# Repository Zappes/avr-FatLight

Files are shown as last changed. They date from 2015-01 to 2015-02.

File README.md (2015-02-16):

The FatLight
======================================

What Is this?
-------------
Short: It's a controller board for RGB LED strips that has a bluetooth and some GPIO pins.

Long: I recently ordered everything needed for the creation of PCBs, i.e. a UV exposure unit,
an etching apparatus, chemicals, boards, the works. As a first project, I wanted to do something
that I could use, that I understood from the electronics perspective and that could easily be
done on a one-sided PCB without solder mask. A controller for RGB strips seemed to be a good idea, so here we go. :)

**WARNING IF YOU WANT TO BUILD THIS**
Make sure that the pinout of your Bluetooth module matches the pinout on the board. I have three different HC-05 modules in my parts bin, and every type has a different pinout ... This sucks enormously, and if I didn't have those modules lying around, I'd use a pure HC-05 module instead of the breakouts i have now.

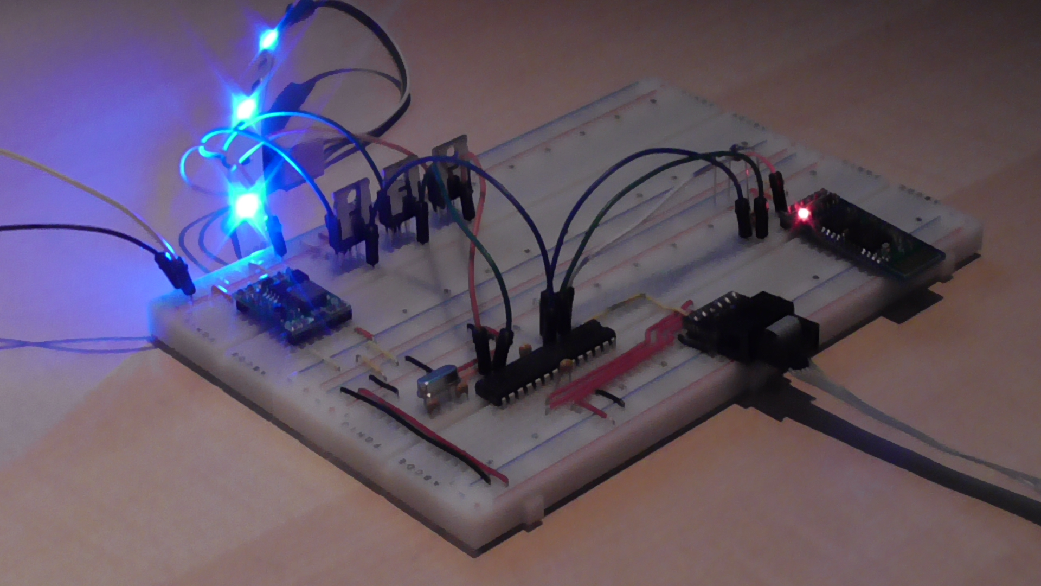
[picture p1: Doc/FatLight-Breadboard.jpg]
Image of the FatLight prototype


How can I control it?
---------------------
It's simple. Connect to the FatLight using a serial terminal over the Bluetooth connection, connection parameters are 9600 8N1, no handshake. The modules have their default pin set to 1234, so use that pin. After connecting, the following commands are supported:

| Command | Parameter | Description |
|---|---|---|
| status | | Prints the current settings. |
| mode | 0-2 | 0: direct color, 1: fade, 2: random |
| on | | Switches the light on | 
| off | | Switches the light off |
| step | 00-FF | Size of the fading steps when fading  |
| set | color | Sets the target color in mode 0 and 1 |
| delay | 00-FF | Greater delays make slower fades |
| level | 00-FF | Brightness in mode 2; 0 is random |
| store | 00-05 | Store current settings in slot 0-5 |
| load | 00-05 | Load settings from slot 0-5 | 
| bt_getname | | Prints the name of the BT module |
| bt_setname | string | Sets the name of the BT module |
| bt_getpass | | Prints the current BT PIN |
| bt_setpass | string | Sets the BT PIN; best use 4 digits |

Color parameters are given as 24 bit hex codes, i.e. 00FF00 for green. Other numeric parameters are also in hex notation. String parameters may never contain whitespace.

Where can I learn more?
-----------------------
[There's a playlist on Youtube.](https://www.youtube.com/playlist?list=PLFFlJlvZ--Pn7IzDO5DFNhvppb0ZImLEq) It's in German, I'm afraid.

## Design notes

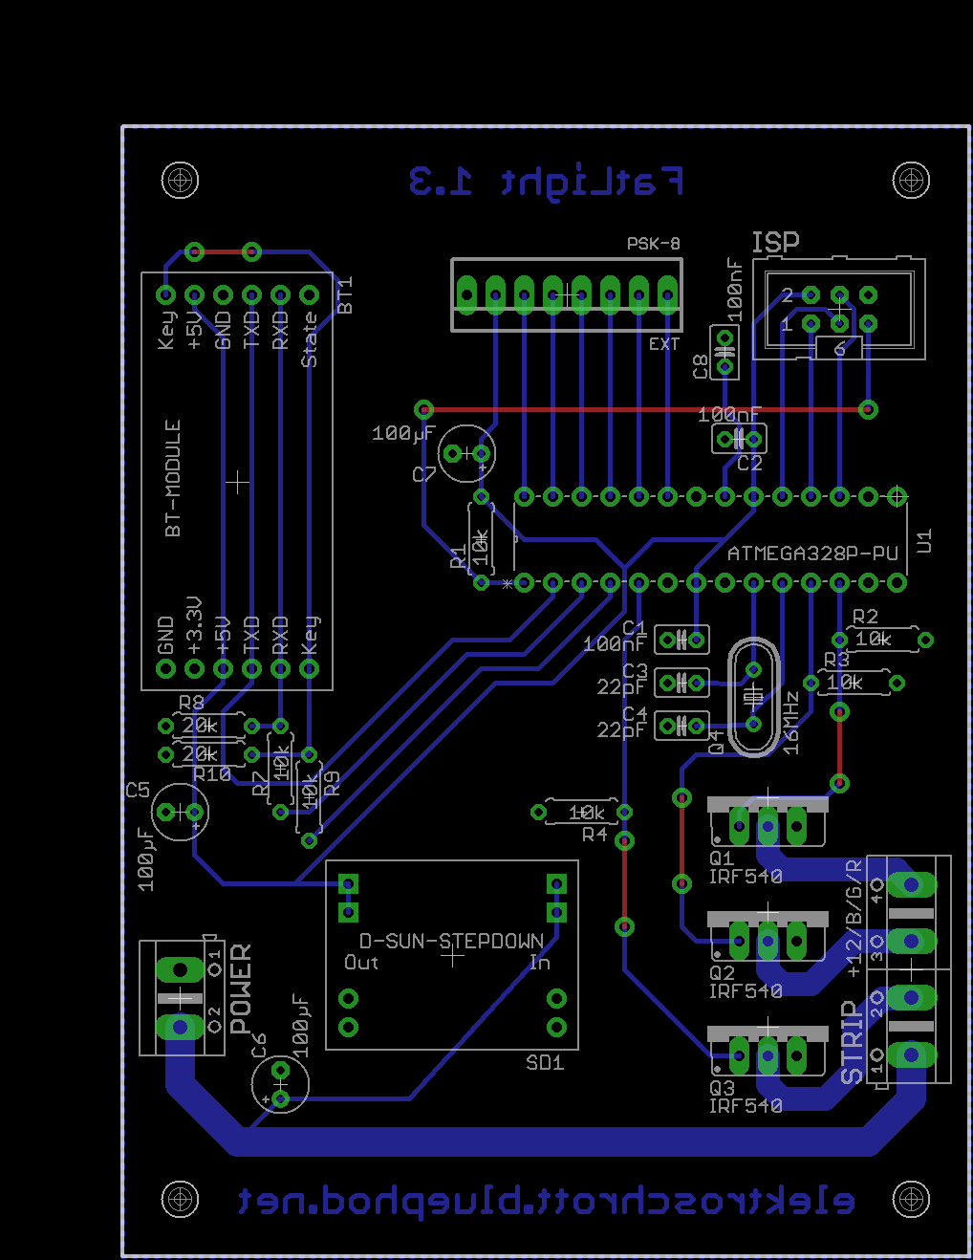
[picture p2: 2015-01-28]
Doc/FatLight-Layout.png

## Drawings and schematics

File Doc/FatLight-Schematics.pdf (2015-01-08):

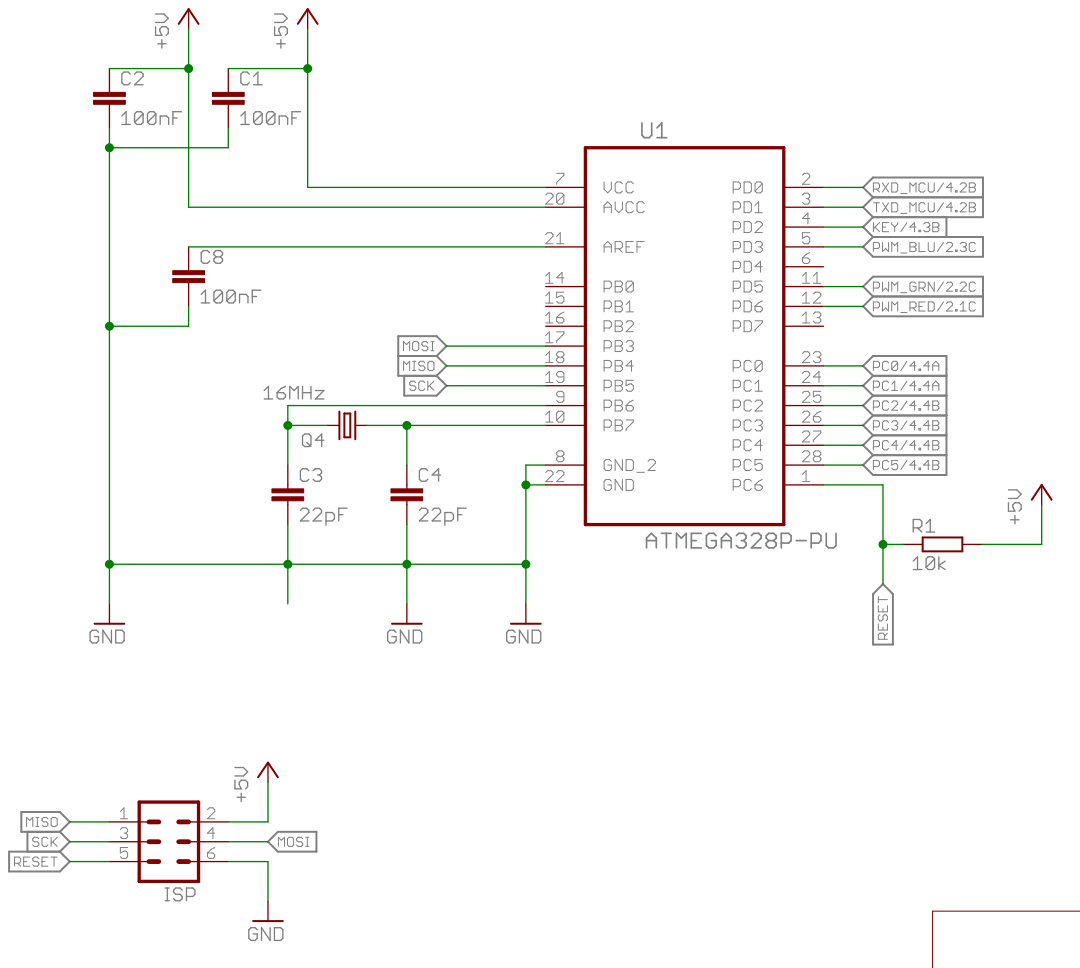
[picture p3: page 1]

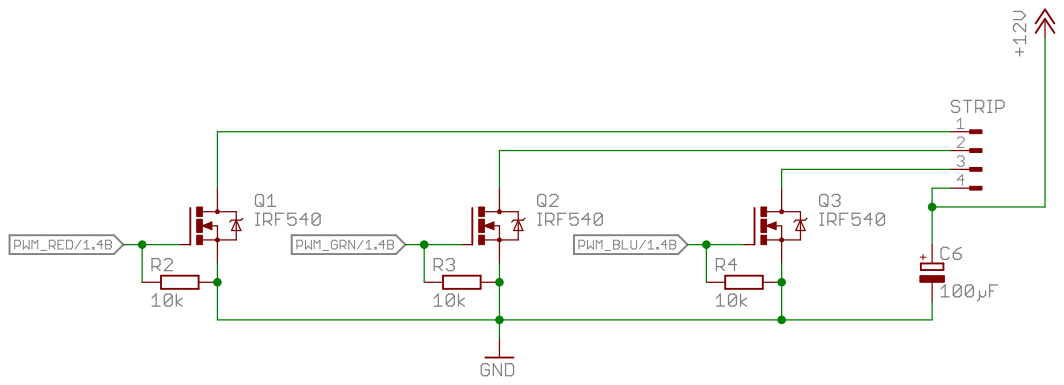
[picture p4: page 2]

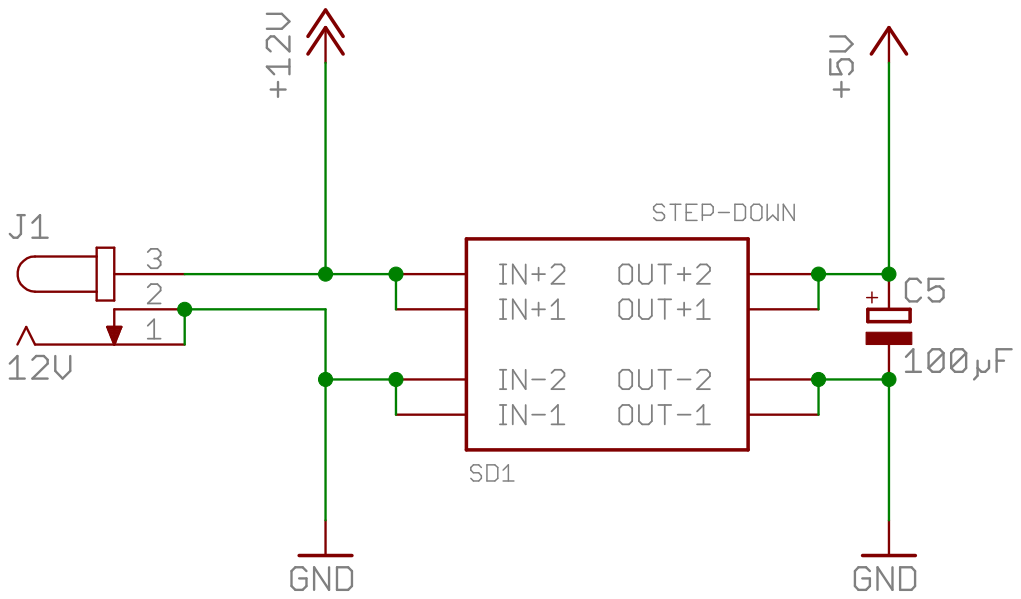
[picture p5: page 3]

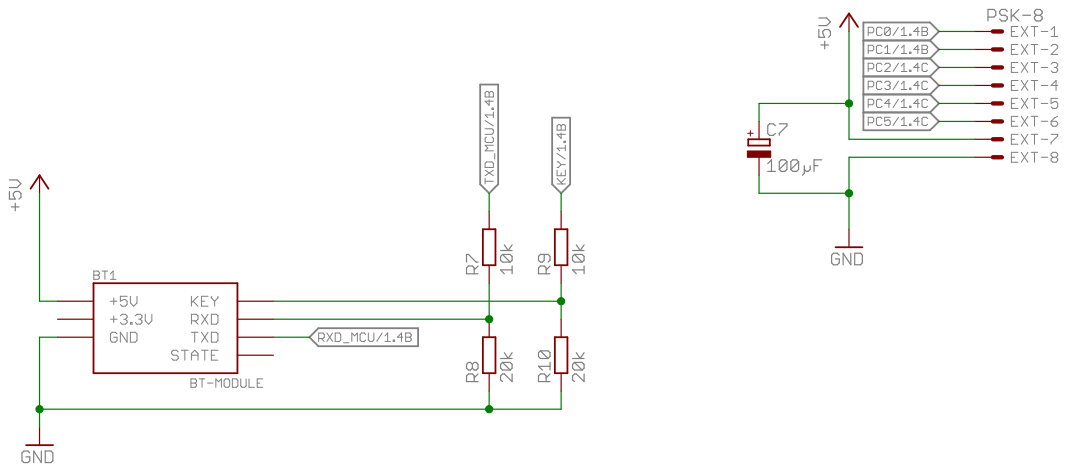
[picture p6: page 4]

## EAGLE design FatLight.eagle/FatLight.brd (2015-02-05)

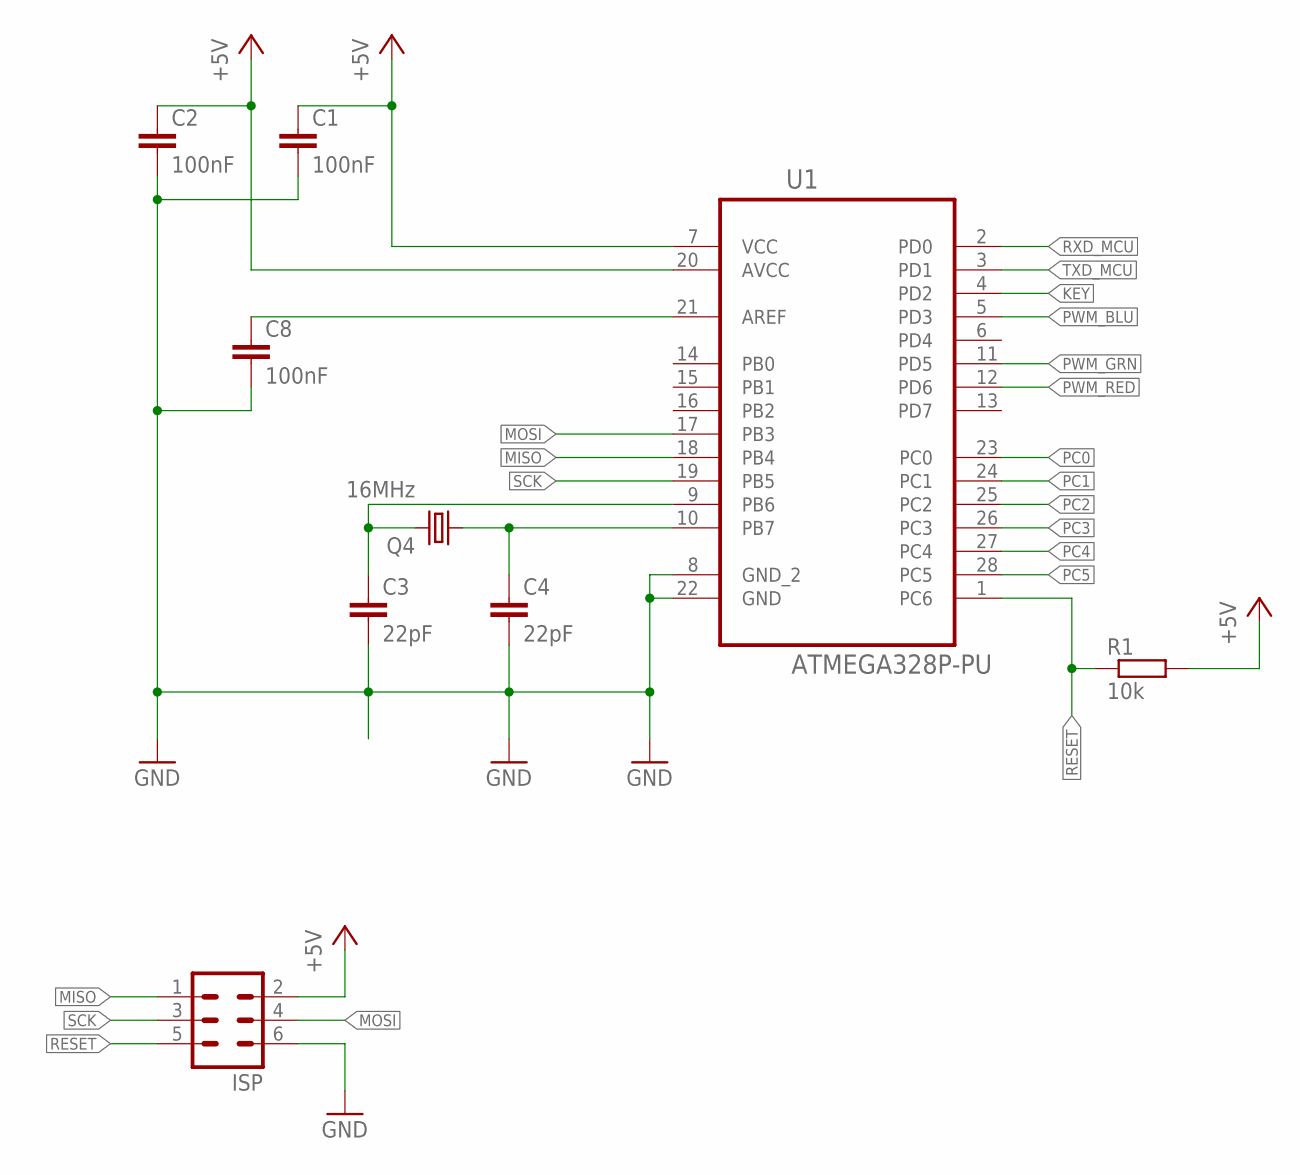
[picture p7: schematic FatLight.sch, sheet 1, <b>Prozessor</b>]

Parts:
C1, C2, C8: 100nF; C025-025X050
C3, C4: 22pF; C025-025X050
ISP: ML6
Q4: 16MHz; HC49/S
R1: 10k; 0207/7
U1: ATMEGA328P-PU; DIP254P762X457-28

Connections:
+5V: C1.1, C2.1, ISP.2, R1.2, U1.7 (VCC), U1.20 (AVCC); also elsewhere on the board
GND: C1.2, C2.2, C3.2, C4.2, C8.2, ISP.6, U1.8 (GND_2), U1.22 (GND); also elsewhere on the board
KEY: U1.4 (PD2); also elsewhere on the board
MISO: ISP.1, U1.18 (PB4)
MOSI: ISP.4, U1.17 (PB3)
unnamed: C4.1, Q4.1, U1.10 (PB7)
unnamed: C3.1, Q4.2, U1.9 (PB6)
unnamed: C8.1, U1.21 (AREF)
PC0: U1.23 (PC0); also elsewhere on the board
PC1: U1.24 (PC1); also elsewhere on the board
PC2: U1.25 (PC2); also elsewhere on the board
PC3: U1.26 (PC3); also elsewhere on the board
PC4: U1.27 (PC4); also elsewhere on the board
PC5: U1.28 (PC5); also elsewhere on the board
PWM_BLU: U1.5 (PD3); also elsewhere on the board
PWM_GRN: U1.11 (PD5); also elsewhere on the board
PWM_RED: U1.12 (PD6); also elsewhere on the board
RESET: ISP.5, R1.1, U1.1 (PC6)
RXD_MCU: U1.2 (PD0); also elsewhere on the board
SCK: ISP.3, U1.19 (PB5)
TXD_MCU: U1.3 (PD1); also elsewhere on the board

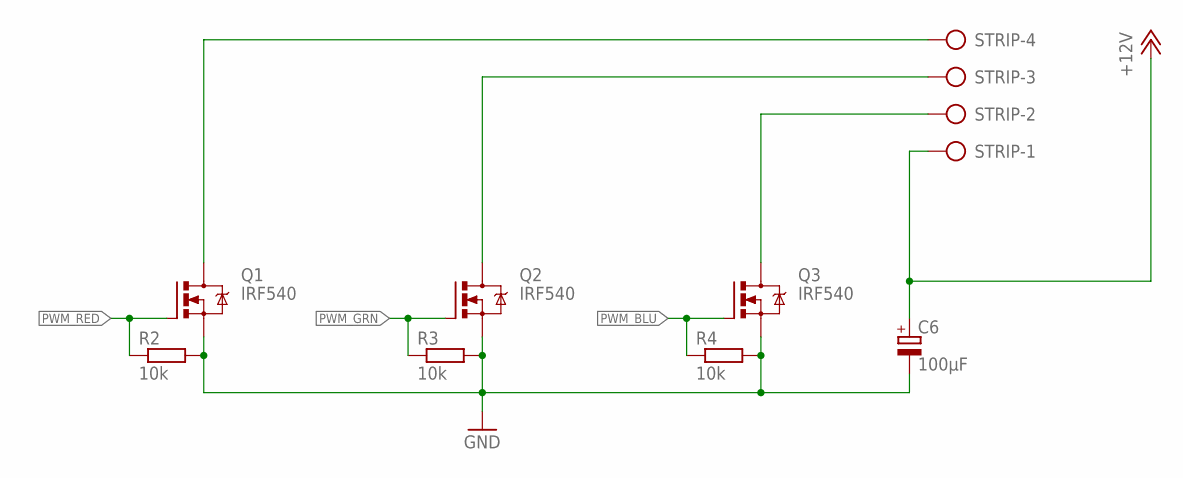
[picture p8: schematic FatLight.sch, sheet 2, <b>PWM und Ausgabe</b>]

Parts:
C6: 100µF; E2,5-5
Q1, Q2, Q3: IRF540; TO220BV
R2, R3, R4: 10k; 0207/7
STRIP: AK500/4

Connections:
+12V: C6.+, STRIP.1; also elsewhere on the board
GND: C6.-, Q1.S, Q2.S, Q3.S, R2.2, R3.2, R4.2; also elsewhere on the board
PWM_BLU: Q3.G, R4.1; also elsewhere on the board
PWM_GRN: Q2.G, R3.1; also elsewhere on the board
PWM_RED: Q1.G, R2.1; also elsewhere on the board
STRIP_BLU: Q3.D, STRIP.2
STRIP_GRN: Q2.D, STRIP.3
STRIP_RED: Q1.D, STRIP.4

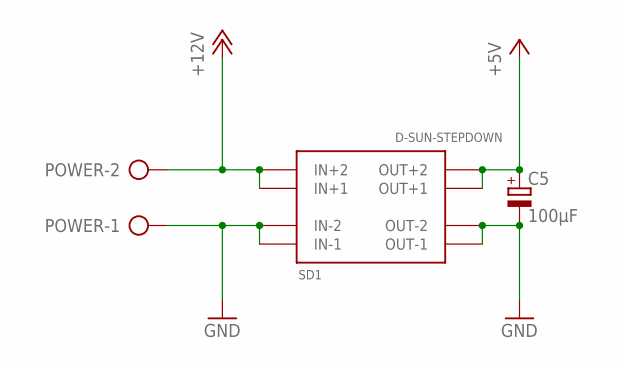
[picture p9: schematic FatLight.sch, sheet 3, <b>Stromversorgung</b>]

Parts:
C5: 100µF; E2,5-5
POWER: AK500/2
SD1: D-SUN-STEPDOWN; STEPDOWN-21X16

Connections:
+5V: C5.+, SD1.OUT+1, SD1.OUT+2; also elsewhere on the board
+12V: POWER.2, SD1.IN+1, SD1.IN+2; also elsewhere on the board
GND: C5.-, POWER.1, SD1.IN-1, SD1.IN-2, SD1.OUT-1, SD1.OUT-2; also elsewhere on the board

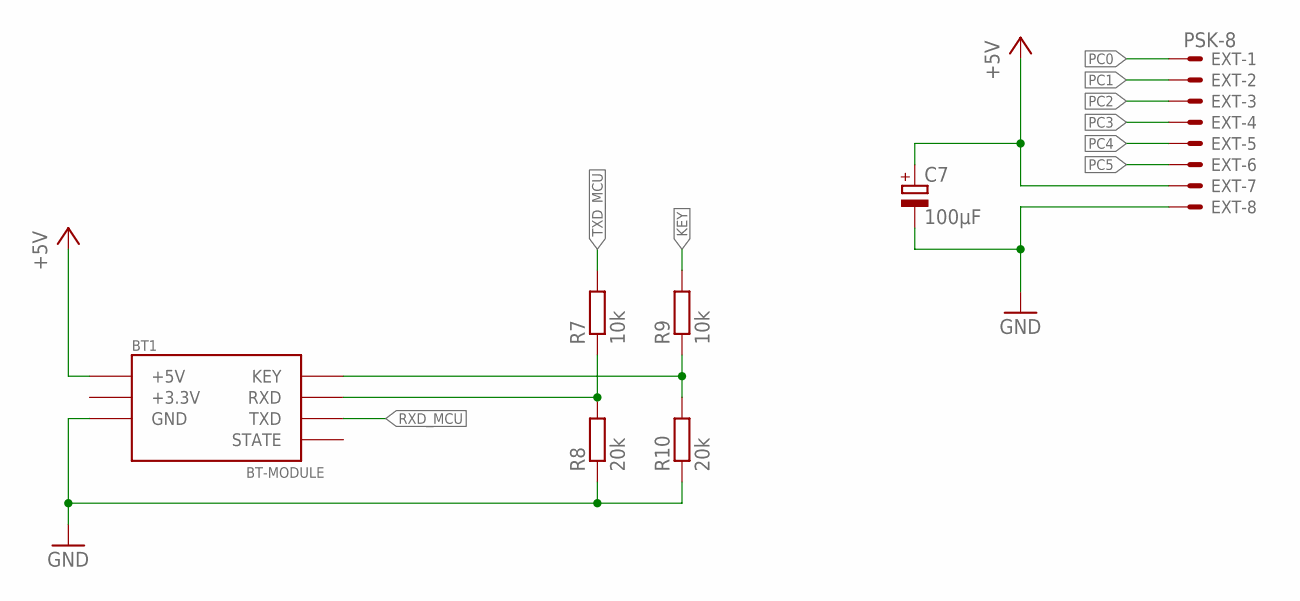
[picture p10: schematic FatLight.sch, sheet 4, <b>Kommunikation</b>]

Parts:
BT1: BT-MODULE; HC-05-6PIN
C7: 100µF; E2,5-5
EXT: PSK-8; 22-23-2081
R7, R9: 10k; 0207/7
R8, R10: 20k; 0207/7

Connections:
+3.3V: BT1.+3.3V
+5V: BT1.+5V, BT1.+5V1 (+5V), C7.+, EXT.7; also elsewhere on the board
GND: BT1.GND, BT1.GND1 (GND), C7.-, EXT.8, R8.1, R10.1; also elsewhere on the board
KEY: R9.2; also elsewhere on the board
unnamed: BT1.KEY, BT1.KEY1 (KEY), R9.1, R10.2
unnamed: BT1.RXD, BT1.RXD1 (RXD), R7.1, R8.2
PC0: EXT.1; also elsewhere on the board
PC1: EXT.2; also elsewhere on the board
PC2: EXT.3; also elsewhere on the board
PC3: EXT.4; also elsewhere on the board
PC4: EXT.5; also elsewhere on the board
PC5: EXT.6; also elsewhere on the board
RXD_MCU: BT1.TXD, BT1.TXD1 (TXD); also elsewhere on the board
TXD_MCU: R7.2; also elsewhere on the board

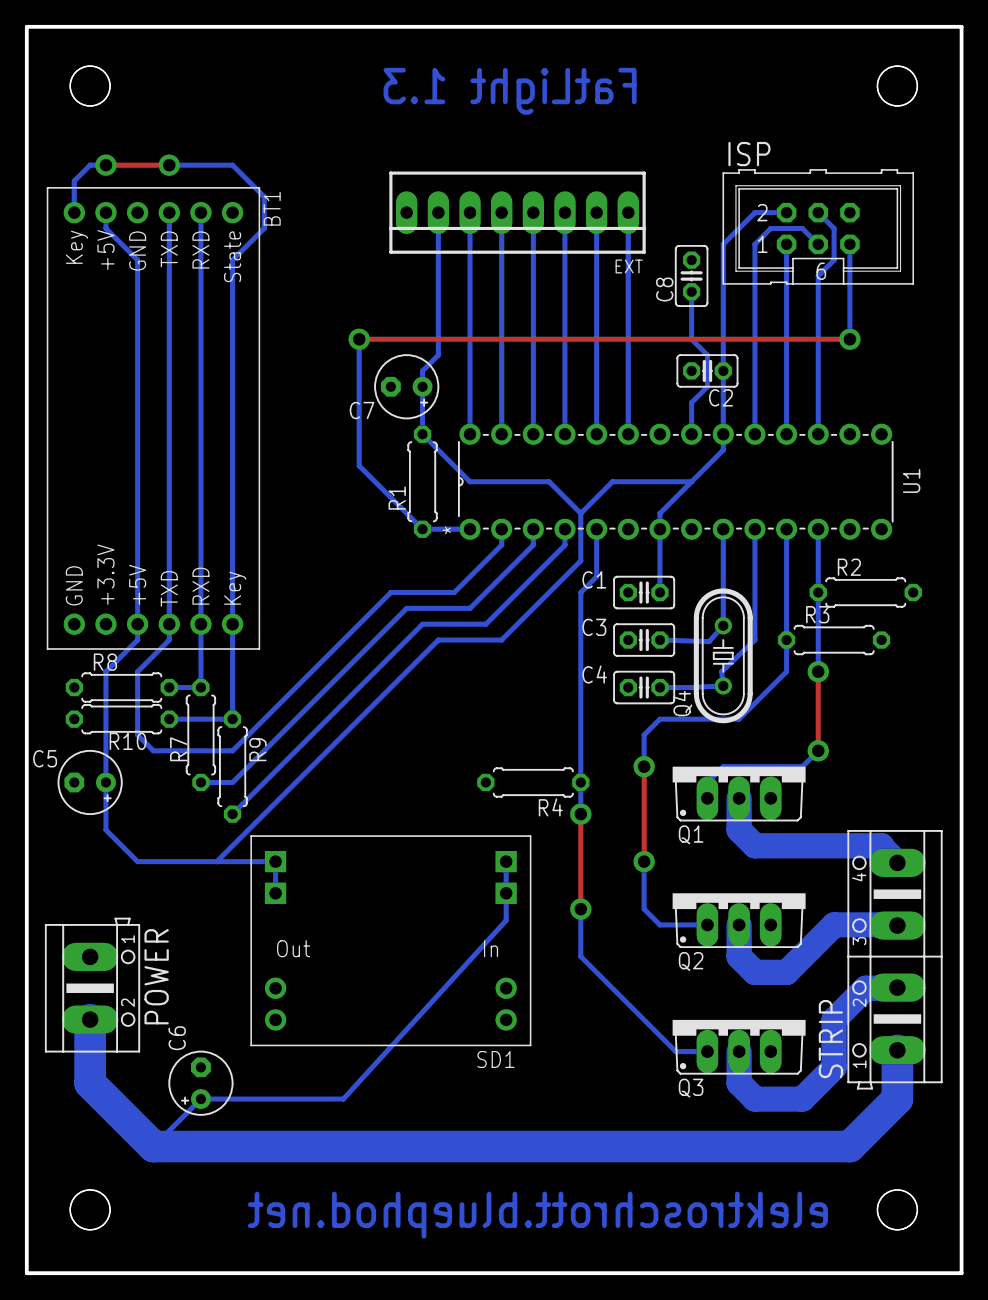
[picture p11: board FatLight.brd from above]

Board: 2 copper layers, 75.0 x 100.0 mm, 27 parts (0 on the bottom side), 27 nets.

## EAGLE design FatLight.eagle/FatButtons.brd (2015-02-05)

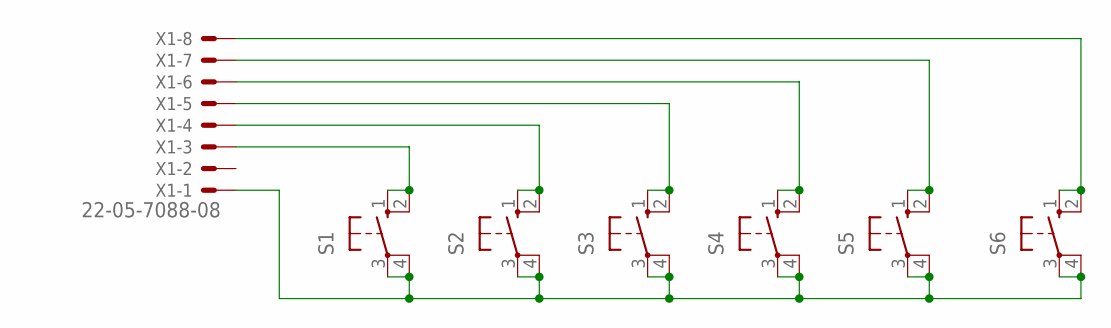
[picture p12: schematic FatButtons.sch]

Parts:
S1, S2, S3, S4, S5, S6: 10-XX; B3F-10XX
X1: 22-05-7088-08; 7395-08

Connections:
unnamed: S1.3, S1.4 (P1), S2.3, S2.4 (P1), S3.3, S3.4 (P1), S4.3, S4.4 (P1), S5.3, S5.4 (P1), S6.3, S6.4 (P1), X1.1
unnamed: S1.1 (S), S1.2 (S1), X1.3
unnamed: S2.1 (S), S2.2 (S1), X1.4
unnamed: S3.1 (S), S3.2 (S1), X1.5
unnamed: S4.1 (S), S4.2 (S1), X1.6
unnamed: S5.1 (S), S5.2 (S1), X1.7
unnamed: S6.1 (S), S6.2 (S1), X1.8

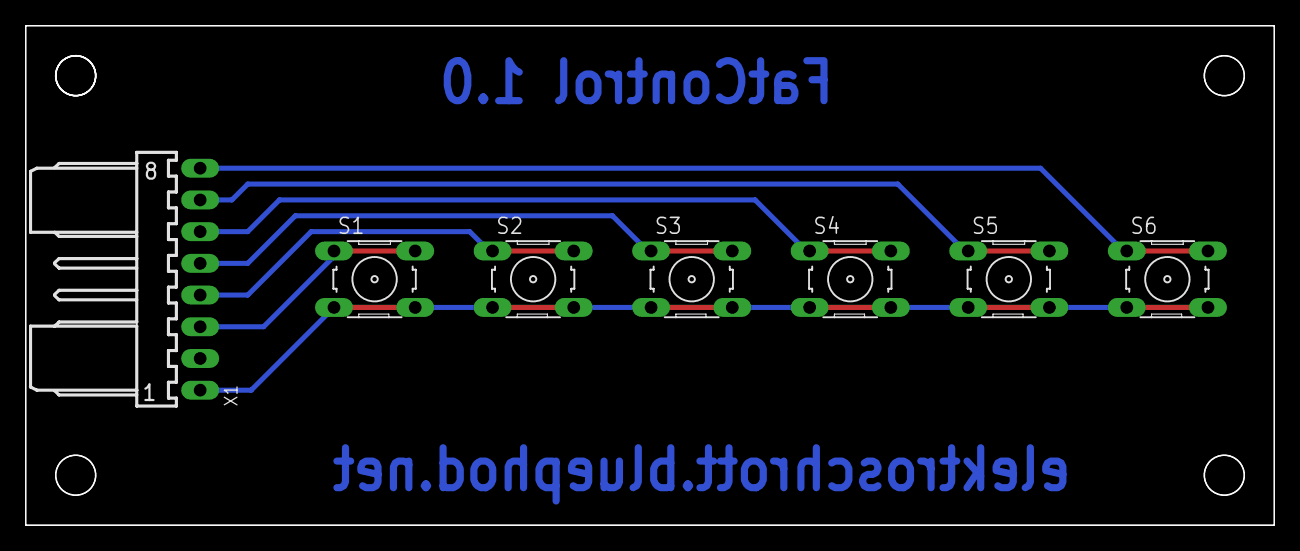
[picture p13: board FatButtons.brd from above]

Board: 2 copper layers, 100.0 x 40.0 mm, 7 parts (0 on the bottom side), 7 nets.

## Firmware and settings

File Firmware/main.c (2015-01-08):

/*
 * Controller code for a device that reads analog sensor values and sleeps
 * while it isn't used. Check the README at Github for more information.
 *
 * Written by Gregor Ottmann, https://github.com/Zappes
 */
#include <avr/io.h>
#include <avr/interrupt.h>
#include <util/delay.h>

#include "lib/stripcontrol.h"
#include "lib/uart.h"
#include "lib/control.h"
#include "lib/animation.h"
#include "lib/bluetooth.h"

#include "lib/persistence.h"
#include "lib/buttons.h"

int main(void)
{
	strip_init();
	uart_init();
	control_init();
	anim_init();
	bt_init();
	buttons_init();

	persistence_restore(persistence_get_current_slot());

	// required for serial input and the animation loop to work!
	sei();

	while(1)
	{
		buttons_process();
	}

	return 0;
}

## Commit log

2014-12-31 Bluetooth-Modul besser im Layout angeordnet.
    [FatLight.brd]
2015-01-02 Vias und Restringe vergrößert, richtige Widerstandsgrößen verwendet, Platinengröße angepasst, Kondensator für Ext-Konnektor eingefügt.
    [FatLight.brd, FatLight.sch]
2015-01-02 Optimierung des Boards
    [FatLight.brd, FatLight.sch]
2015-01-05 Implemented Bluetooth control
    [FatLight.brd, FatLight.sch]
2015-01-05 Added animation code and support for renaming the BT device
2015-01-06 Added a pictire of the prototype
2015-01-07 Added support for Buttons on PC0-PC2 that can restore slots 0-2. (connect to GND)
2015-01-08 Updated Board and Schmeatics so either of two different HC-05 module types can be fitted. Bugfixes.
    [FatLight.brd, FatLight.sch]
2015-01-10 Implemented the on/off commands and remapped button 2 to power toggling instead of loading profile 2.
2015-01-10 Made sure that the corect color is used when re-enabling the strip after switching it off in disco mode.
2015-01-11 Lowered PWM frequency to 1kHz
2015-01-17 Cap setting for random values added, optimized board layout.
    [FatLight.brd]
2015-01-18 Fixed the dimensions of the d-sun step-down module.
    [FatLight.brd, FatLight.sch]
2015-01-25 Neue Revision des Boards, Firmware mit Farbeffekten
    [FatLight.brd, FatLight.sch]
2015-01-28 Neue Board-Revision 1.3 mit stark optimiertem Layout und korrigiertem BT-Pinout
    [FatLight.brd, FatLight.sch]
2015-01-28 Bestückungsdruck verbessert
    [FatLight.brd]
2015-02-05 FatButtons hinzugefügt, mehr Speicherlots freigegeben, Level 0 für Animationen mit zufälliger Helligkeit.
    [FatButtons.brd, FatButtons.sch, FatLight.brd]
